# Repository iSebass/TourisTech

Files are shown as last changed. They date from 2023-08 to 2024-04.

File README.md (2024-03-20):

# TuristTech

## Introducción

En el contexto de un mundo cada vez más consciente de la importancia de la sostenibilidad y la conservación del medio ambiente, surge un proyecto visionario que busca revolucionar la industria del ecoturismo en Colombia. En este proyecto encontrarás la implementación de una red IoT para monitorear y controlar dispositivos en un ecotel, uniendo la tecnología con la conservación del entorno natural.

## Metodología 

En el marco de este proyecto, la metodología establece las fases fundamentales desde la planificación inicial hasta la culminación del proceso, garantizando una gestión eficaz y coherente en cada etapa. Esta metodología se sustenta en la colaboración interdisciplinaria entre especialistas en tecnología, turismo y conservación, integrando además prácticas ágiles y flexibles para ajustarse a las exigencias y dinámicas del entorno en constante cambio. 

1. **Implementación de Alexa**: La implementación de Alexa marca un avance significativo en el proyecto, al ofrecer una interacción innovadora para los usuarios del ecotel. Este punto de la metodología se enfoca en dos etapas cruciales:
   
    1. **Configuración inicial de Alexa**: Se trata de preparar y conectar los dispositivos necesarios, configurar la aplicación y la cuenta asociada. Esta etapa establece la base tecnológica esencial para la interacción con el asistente de voz. Para la configuración inicial de Alexa, se deben seguir los siguientes pasos:
   
       1. **Descargar la aplicación de Alexa:**
          - Si estás usando un dispositivo Android, descarga la aplicación de Alexa desde [Google Play Store](https://play.google.com/store/apps/details?id=com.amazon.dee.app&pcampaignid=web_share "Google Play Store").
          - Si utilizas un dispositivo Apple, encuentra la aplicación en [App Store](https://apps.apple.com/ni/app/amazon-alexa/id944011620 "App Store").
       
       2. **Vincular o registrar una cuenta de Amazon:**
          - Si aún no tienes una cuenta de Amazon, regístrate.
          - Inicia sesión con tu cuenta de Amazon en la aplicación de Alexa.
       
       3. **Instalar una Skill:**
          - Dentro de la aplicación de Alexa, dirígete a la sección de "Skills" y selecciona "Buscar Skills".
          - Busca la Skill "Ben Hardill - Node-RED" o utiliza este [enlace directo](https://www.amazon.com/Ben-Hardill-Node-RED/dp/B01N0D97FZ) para instalarla.
          - Una vez instalada, sigue las instrucciones para habilitar la Skill y conceder los permisos necesarios para vincular Alexa con Node-RED.
 
   2. **Integración de Alexa con Node-RED**: Aquí, se exploran los pasos para conectar Alexa a Node-RED, una plataforma que facilita la automatización y el control de dispositivos IoT. Se configuran los nodos correspondientes para una comunicación efectiva entre ambos sistemas.

Estas etapas son fundamentales para aprovechar al máximo la implementación de Alexa, mejorando la experiencia del ecoturismo. Una cuidadosa planificación y ejecución en estas áreas sientan las bases para una integración exitosa del asistente de voz en el entorno del ecotel.

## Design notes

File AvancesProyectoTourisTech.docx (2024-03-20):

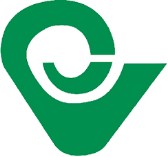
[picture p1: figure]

# UNIDAD CENTRAL DEL VALLE DEL CAUCA - VICEREPTORIA DE INVESTIGACIÓN Y PROYECCIÓN SOCIAL

### AULA STEAM- INFORME TOURISTECH

Abstract: This project focuses on implementing an IoT network to monitor and control devices in an ecotel, aiming to integrate technology with environmental conservation in Colombia. Although not yet implemented in a real ecotourism environment, significant progress has been made with a pilot model at Universidad Central del Valle. Using ESP32 devices, a Mosquito broker, a Node-RED dashboard, and Alexa voice assistance, control of room lighting and visualization of environmental variables have been achieved. The project stands out for its ability to enhance visitor experience while promoting natural resource conservation.

Resumen: El proyecto consiste en la implementación de una red IoT para monitorear y controlar dispositivos en un ecotel, con el objetivo de unir la tecnología con la conservación del entorno natural en Colombia. Aunque aún no se ha materializado en un entorno ecoturístico real, se ha avanzado significativamente con un modelo piloto en la Universidad Central del Valle. Utilizando dispositivos ESP32, un broker Mosquito, una dashboard en Node-RED y la asistencia de voz de Alexa, se ha logrado controlar la iluminación de las habitaciones y visualizar variables ambientales. El proyecto destaca por su capacidad para mejorar la experiencia del visitante mientras se promueve la conservación de los recursos naturales.

I. INTRODUCCIÓN

En el contexto de un mundo cada vez más consciente de la importancia de la sostenibilidad y la conservación del medio ambiente, surge un proyecto visionario que busca revolucionar la industria del ecoturismo en Colombia. Este informe presenta los progresos y adelantos alcanzados en la creación de un concepto innovador: la implementación de una red IoT para monitorear y controlar dispositivos en un ecotel, uniendo la tecnología con la conservación del entorno natural.

Aunque el proyecto aún no se ha materializado en un entorno ecoturístico real, se ha logrado un avance significativo mediante la creación de un modelo piloto en el aula STEAM de la Vicerrectoría de Investigación de la Universidad Central del Valle. Este espacio de vanguardia ha servido como campo de pruebas para explorar las posibilidades y desafíos de integrar la tecnología IoT en un entorno de ecoturismo.

El proyecto se basa en la utilización de dispositivos ESP32 con conectividad WiFi, junto con un broker Mosquito y una dashboard desarrollada en Node-RED, para crear una red robusta y versátil. Además, se ha implementado la asistencia de voz a través de

Alexa, agregando una capa de interacción intuitiva para los usuarios.

A pesar de su ubicación en un entorno académico, el proyecto ha logrado avances significativos, incluyendo la capacidad de controlar la iluminación de las habitaciones y visualizar variables ambientales como temperatura, altitud, presión y calidad del aire. Estos logros sientan las bases para futuras aplicaciones en el campo del ecoturismo, ofreciendo un enfoque innovador que busca conciliar la comodidad de los visitantes con la preservación del medio ambiente.

Este informe detallará los aspectos técnicos del proyecto, así como los pasos a seguir para llevarlo del laboratorio al campo. Se discutirán los desafíos enfrentados durante el proceso de desarrollo y se explorarán las oportunidades para expandir y perfeccionar el proyecto. Se analizarán también los beneficios potenciales que esta iniciativa puede aportar tanto a la industria del ecoturismo como al medio ambiente en general, destacando su capacidad para mejorar la experiencia del visitante mientras se promueve la conservación de los recursos naturales.

Aunque el camino hacia la implementación completa en un ecotel real presenta desafíos adicionales, el modelo piloto desarrollado en la Universidad Central del Valle representa un paso crucial en la dirección correcta. La colaboración entre expertos en tecnología, conservación y turismo ha sido fundamental para impulsar este proyecto hacia adelante y sentar las bases para su éxito futuro.

En resumen, este informe proporcionará una visión detallada de un proyecto innovador que tiene el potencial de transformar la industria del ecoturismo en Colombia y más allá. A medida que avanzamos hacia un futuro más sostenible, iniciativas como esta demuestran el poder de la tecnología para impulsar el cambio positivo y proteger nuestro precioso entorno natural para las generaciones venideras.

## II. METODOLOGÍA

Implementación de Alexa

1. Registra la misma cuenta de amazon a la pagina que nos proporciona nodered de el nodo de Alexa.
2. Se crea uno dispositivo en el cual se especifica el nombre, el tipo de funcion y la descripción.
3. Se le instala a la Alexa la aplicación de node red para permitir la conexión con el nodo en Node red
4. Se configura a Alexa para que busque nuevos dispositivos en donde aparecerá los creamos anteriormente en la cuenta de nodered-alexa

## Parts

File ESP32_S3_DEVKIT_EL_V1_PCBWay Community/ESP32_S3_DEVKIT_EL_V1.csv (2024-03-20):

Item | Qty | Reference(s) | Product Number | Value | LibPart | Footprint | Datasheet | DNP | Description | Manufacturer | Price
1 | 6 | BT1, BT2, BT3, BT4, SW1, SW2 | PTS636 SK25 SMTR LFS | SW_Push | Switch:SW_Push | Button_Switch_SMD:SW_Tactile_SPST_NO_Straight_CK_PTS636Sx25SMTRLFS | https://www.ckswitches.com/media/2779/pts636.pdf |  | Tactile Switch SPST-NO Top Actuated Surface Mount | C&K | 0.15
2 | 1 | BZ1 | GT-111P | Buzzer | Device:Buzzer | Buzzer_Beeper:Buzzer_12x9.5RM7.6 | https://www.digikey.com/en/supplier-centers/soberton |  | Buzzers Transducer, Externally Driven Magnetic 1.5 V 10mA 2.048kHz 80dB @ 1.5V, 10cm Through Hole PC Pins | Soberton Inc. | 0.65
3 | 10 | C1, C3, C5, C6, C7, C8, C10, C11, C13, C14 | C0603C104K5RAC7867 | 0.1 uF | Device:C | Capacitor_SMD:C_0603_1608Metric_Pad1.08x0.95mm_HandSolder | https://connect.kemet.com:7667/gateway/IntelliData-ComponentDocumentation/1.0/download/datasheet/C0603C104K5RACTU |  | CAP CER 0.1UF 50V X7R 0603 | KEMET | 0.11
4 | 3 | C2, C9, C12 | C1206C106M3PAC7800 | 10 uF | Device:C | Capacitor_SMD:C_1206_3216Metric_Pad1.33x1.80mm_HandSolder | https://connect.kemet.com:7667/gateway/IntelliData-ComponentDocumentation/1.0/download/datasheet/C1206C106M3PACTU |  | CAP CER 10UF 25V X5R 1206 | KEMET | 0.27
5 | 1 | C4 | C1206C105M4RAC7800 | 1 uF | Device:C | Capacitor_SMD:C_1206_3216Metric_Pad1.33x1.80mm_HandSolder | https://connect.kemet.com:7667/gateway/IntelliData-ComponentDocumentation/1.0/download/datasheet/C1206C105M4RAC7800 |  | 1 µF ±20% 16V Ceramic Capacitor X7R 1206 (3216 Metric) | KEMET | 0.17
6 | 1 | D1 | 5988270107F | Green LED | Device:LED | LED_SMD:LED_1206_3216Metric | https://s3-us-west-2.amazonaws.com/catsy.557/Dialight_CBI_data_598-1206_Apr2018.pdf |  | Green 566nm LED Indication - Discrete 2V 1206 (3216 Metric) | Dialight | 0.32
7 | 1 | D2 | NRVA4007T3G | NRVA4007T3G | Diode:MRA4007T3G | Diode_SMD:D_SMA | https://www.onsemi.com/pdf/datasheet/mra4003t3-d.pdf |  | Diode 1000 V 1A Surface Mount SMA | onsemi | 0.41
8 | 4 | D3, D4, D5, D6 | COM-16347 | WS2812B | LED:WS2812B | LED_SMD:LED_WS2812B_PLCC4_5.0x5.0mm_P3.2mm | https://cdn-shop.adafruit.com/datasheets/WS2812B.pdf |  | Addressable Lighting - LED Serial NRZ (Shift Register) Red, Green, Blue (RGB) | SparkFun Electronics | 0.58
9 | 4 | D7, D8, D9, D10 | 5988291107F | Blue LED | Device:LED | LED_SMD:LED_1206_3216Metric | https://s3-us-west-2.amazonaws.com/catsy.557/Dialight_CBI_data_598-1206_Apr2018.pdf |  | Blue 473nm LED Indication - Discrete 3.2V 1206 (3216 Metric) | Dialight | 0.38
10 | 3 | D11, D12, D13 | STPS2L30A | D_Schottky | Device:D_Schottky | Diode_SMD:D_SMA | https://www.st.com/content/ccc/resource/technical/document/datasheet/62/6b/2e/7f/34/cb/43/55/CD00001633.pdf/files/CD00001633.pdf/jcr:content/translations/en.C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 |  | DIODE SCHOTTKY 30V 2A SMA | STMicroelectronics | 0.36
11 | 1 | D14 | 5988210107F | RED LED | Device:LED | LED_SMD:LED_1206_3216Metric | https://s3-us-west-2.amazonaws.com/catsy.557/Dialight_CBI_data_598-1206_Apr2018.pdf |  | Red 635nm LED Indication - Discrete 2V 1206 (3216 Metric) | Dialight | 0.33
12 | 3 | J1, J4, J5 | 2057-BHR-06-VUA-ND | Conn_02x03_IDC | Connector_Generic:Conn_02x03_Odd_Even | Connector_IDC:IDC-Header_2x03_P2.54mm_Vertical | https://app.adam-tech.com/products/download/data_sheet/203218/bhr-xx-vua-data-sheet.pdf |  | Connector Header Through Hole 6 position 0.100" (2.54mm) | Adam Tech | 0.25
13 | 2 | J2, J8 | 0473460001 | USB_B_Micro | Connector:USB_B_Micro | Connector_USB:USB_Micro-B_Molex_47346-0001 | https://tools.molex.com/pdm_docs/sd/473460001_sd.pdf |  | CONN RCPT USB2.0 MICRO B SMD R/A | Molex | 1.17
14 | 2 | J3, J6 | 1734656 | Screw_Terminal_01x02 | Connector:Screw_Terminal_01x02 | TerminalBlock_Phoenix:TerminalBlock_Phoenix_MKDS-1,5-2_1x02_P5.00mm_Horizontal | https://media.digikey.com/PDF/Data%20Sheets/Phoenix%20Contact%20PDFs/1734656.pdf |  | 2 Position Wire to Board Terminal Block Horizontal with Board 0.197" (5.00mm) Through Hole | Phoenix Contact | 1.26
15 | 1 | J7 | 54202-S0803LF | Conn_02x03_Odd_Even | Connector_Generic:Conn_02x03_Odd_Even | Connector_PinHeader_2.54mm:PinHeader_2x03_P2.54mm_Vertical_SMD | https://cdn.amphenol-cs.com/media/wysiwyg/files/drawing/54202.pdf |  | Connector Header Surface Mount 6 position 0.100" (2.54mm) | Amphenol ICC (FCI) | 0.45
16 | 1 | J9 | ED1543-ND | Conn_02x05_Odd_Even | Connector_Generic:Conn_02x05_Odd_Even | Connector_IDC:IDC-Header_2x05_P2.54mm_Vertical | http://www.on-shore.com/wp-content/uploads/2018/04/302-SXX1.pdf |  | Connector Header Through Hole 10 position 0.100" (2.54mm) | On Shore Technology Inc. | 0.33
17 | 1 | K1 | G5Q-1A4 DC5 | G5Q-1A | Relay:G5Q-1A | Relay_THT:Relay_SPST_Omron-G5Q-1A | https://www.omron.com/ecb/products/pdf/en-g5q.pdf |  | General Purpose Relay SPST-NO (1 Form A) 5VDC Coil Through Hole | Omron Electronics Inc-EMC Div | 1.57
18 | 3 | Q1, Q2, Q3 | MMBT2222LT1G | Q_NPN_BEC | Device:Q_NPN_BEC | Package_TO_SOT_SMD:SOT-23-3 | https://www.onsemi.com/pdf/datasheet/mmbt2222lt1-d.pdf |  | Bipolar (BJT) Transistor NPN 30 V 600 mA 250MHz 300 mW Surface Mount SOT-23-3 (TO-236) | onsemi | 0.16
19 | 4 | R1, R2, R3, R5 | ERJ-P08J102V | 1K | Device:R_US | Resistor_SMD:R_1206_3216Metric | https://industrial.panasonic.com/ww/products/pt/general-purpose-chip-resistors/models/ERJ-P08J102V |  | RES SMD 1K OHM 5% 2/3W 1206 | Panasonic Electronic Components | 0.14
20 | 1 | R4 | ERJ-8GEY0R00V | 0R | Device:R_US | Resistor_SMD:R_1206_3216Metric | https://industrial.panasonic.com/ww/products/pt/general-purpose-chip-resistors/models/ERJ8GEYJ331V |  | 0 Ohms Jumper Chip Resistor 1206 (3216 Metric) Automotive AEC-Q200 Thick Film | Panasonic Electronic Components | 0.14
21 | 4 | R6, R7, R12, R13 | ERJ-8GEYJ103V | 10K | Device:R_US | Resistor_SMD:R_1206_3216Metric | https://industrial.panasonic.com/ww/products/pt/general-purpose-chip-resistors/models/ERJ-8GEYJ103V |  | RES SMD 10K OHM 5% 1/4W 1206 | Panasonic Electronic Components | 0.12
22 | 6 | R8, R9, R10, R11, R14, R15 | ERJ-8GEYJ331V | 330R | Device:R_US | Resistor_SMD:R_1206_3216Metric | https://industrial.panasonic.com/ww/products/pt/general-purpose-chip-resistors/models/ERJ8GEYJ331V |  | RES SMD 330 OHM 5% 1/4W 1206 | Panasonic Electronic Components | 0.14
23 | 4 | RV1, RV2, RV3, RV4 | 3386P-1-104LF | 100K | Device:R_Potentiometer_Trim_US | Potentiometer_THT:Potentiometer_Bourns_3386P_Vertical | https://www.vishay.com/docs/51016/t73.pdf |  | 100 kOhms 0.5W, 1/2W PC Pins Through Hole Trimmer Potentiometer Cermet 1.0 Turn Top Adjustment | Bourns Inc. | 1.61
24 | 1 | U1 | CH340C | CH340C | Interface_USB:CH340C | Package_SO:SOIC-16_3.9x9.9mm_P1.27mm | https://datasheet.lcsc.com/szlcsc/Jiangsu-Qin-Heng-CH340C_C84681.pdf |  | USB to serial port chip | WCH | 0.73
25 | 1 | U2 | ESP32-S3-WROOM-1-N8R2 | ESP32-S3-WROOM-1 | PCM_Espressif:ESP32-S3-WROOM-1 | PCM_Espressif:ESP32-S3-WROOM-1 | https://www.espressif.com/sites/default/files/documentation/esp32-s3-wroom-1_wroom-1u_datasheet_en.pdf |  | WiFi 802.11a/b/g/n, Bluetooth v5.0 Transceiver Module 2.4GHz PCB Trace | Espressif Systems | 3.35
26 | 1 | U3 | AZ1117CH-3.3TRG1 | 3.3v 1A | Regulator_Linear:AZ1117-3.3 | Package_TO_SOT_SMD:SOT-223-3_TabPin2 | https://www.diodes.com/assets/Datasheets/AZ1117C.pdf |  | IC REG LINEAR 3.3V 1A SOT223 | Diodes Incorporated | 0.45

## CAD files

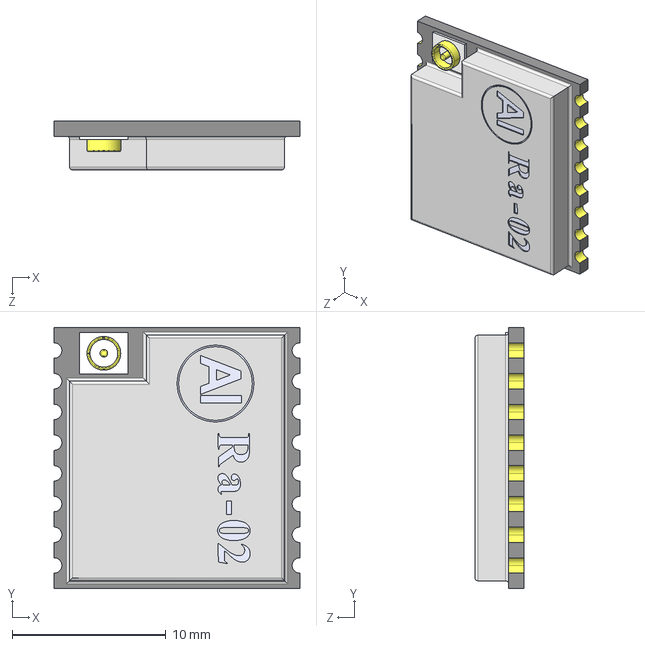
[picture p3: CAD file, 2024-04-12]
ESP32_S3_DEVKIT_EL_V1_PCBWay Community/3D MODELS/User Library-RA-02-2.STEP
16.0 x 17.0 x 3.20 mm

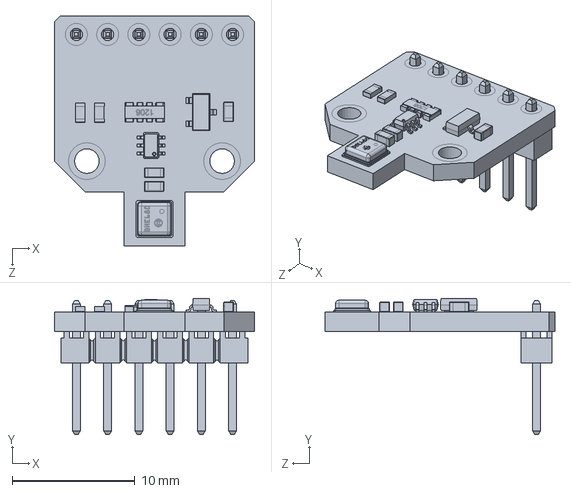
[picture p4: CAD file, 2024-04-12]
PCB/ProyectoTuristech Modulo 01/Modelos3d/CJMCU-680.SLDPRT
16.3 x 11.1 x 18.7 mm

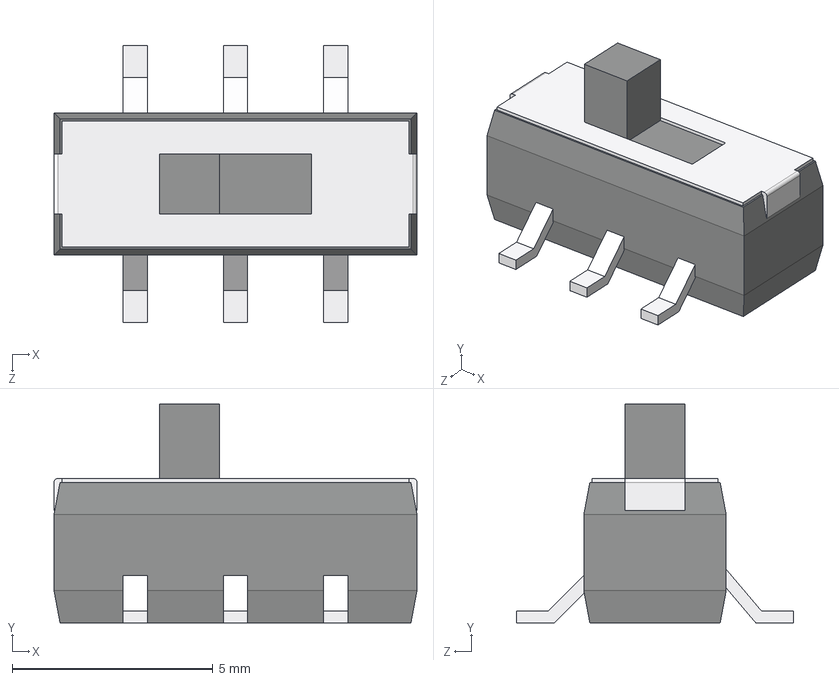
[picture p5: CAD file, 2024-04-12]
ESP32_S3_DEVKIT_EL_V1_PCBWay Community/3D MODELS/User Library-smd_slide_switch.STEP
9.05 x 5.45 x 6.90 mm

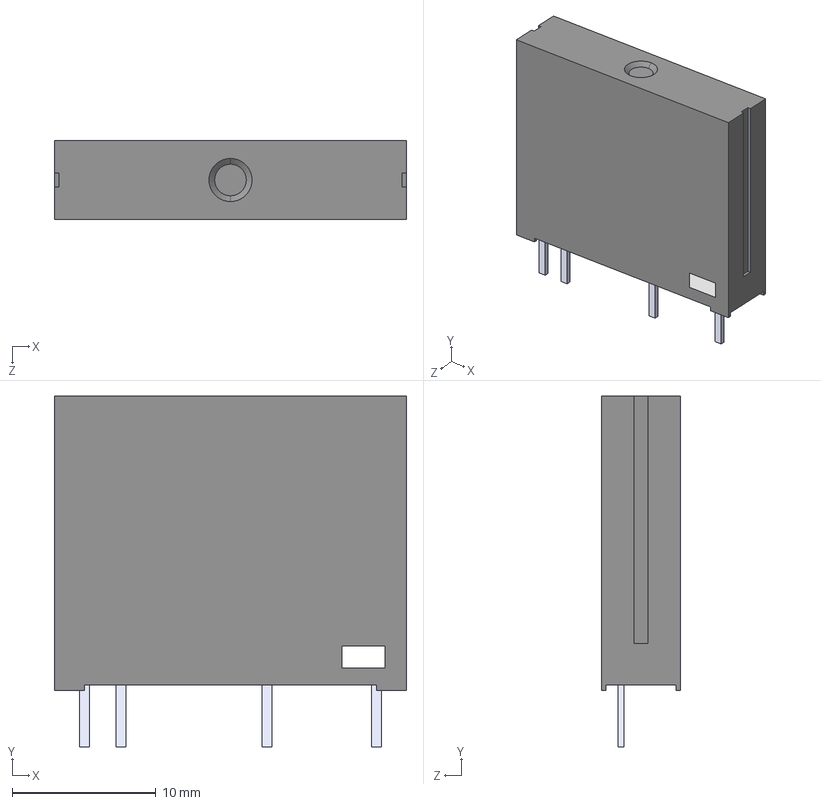
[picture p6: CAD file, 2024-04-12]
PCB/ProyectoTuristech Modulo 01/Modelos3d/G3MB-202P.step
24.5 x 24.4 x 5.50 mm

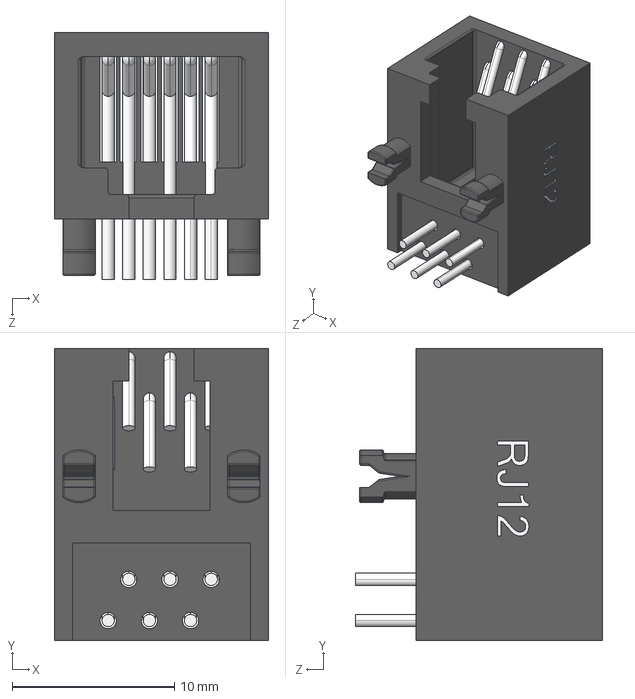
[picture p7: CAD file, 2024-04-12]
ESP32_S3_DEVKIT_EL_V1_PCBWay Community/3D MODELS/User Library-RJ12_54601-906WPLF.STEP
13.2 x 18.0 x 15.2 mm

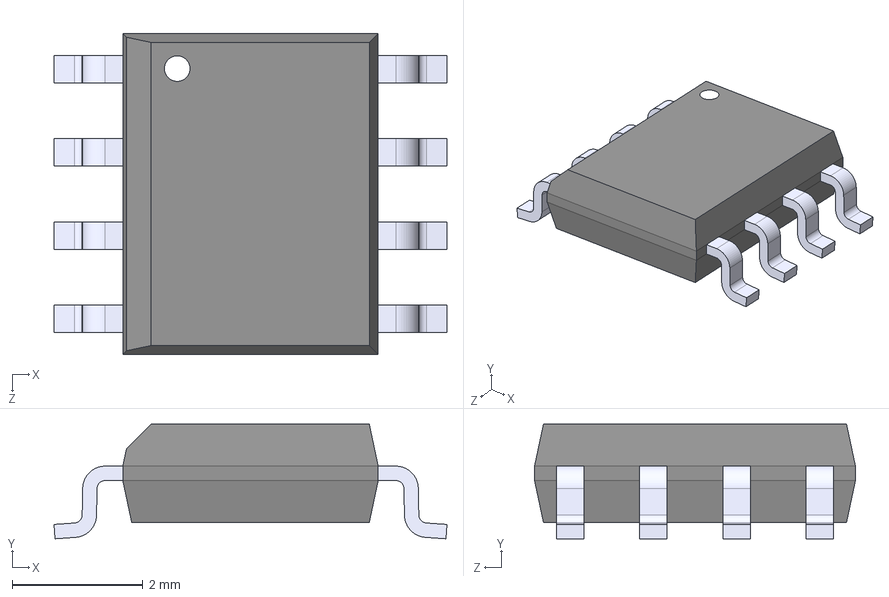
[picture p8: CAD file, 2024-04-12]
ESP32_S3_DEVKIT_EL_V1_PCBWay Community/3D MODELS/LM393D.STEP
6.00 x 1.75 x 4.90 mm

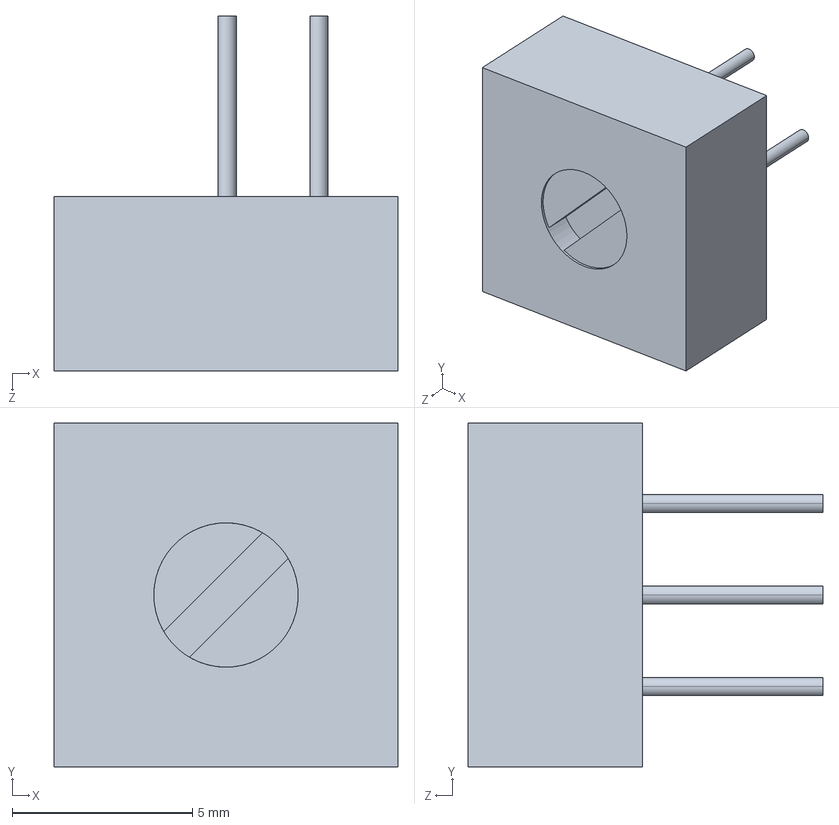
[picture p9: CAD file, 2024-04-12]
ESP32_S3_DEVKIT_EL_V1_PCBWay Community/3D MODELS/CircuitWorks-CERMET TRIMMER SINGLE TURN 10MM 500MW TOP ADJUST 1.STEP
9.53 x 9.53 x 9.83 mm

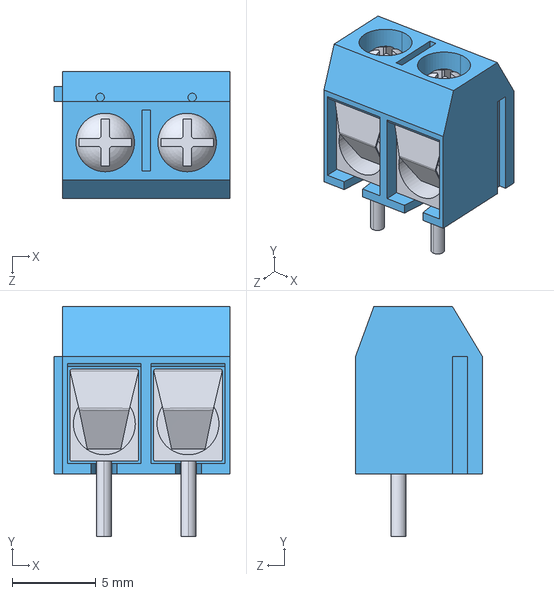
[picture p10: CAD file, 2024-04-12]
ESP32_S3_DEVKIT_EL_V1_PCBWay Community/3D MODELS/User Library-bornera-1.STEP
10.5 x 13.8 x 7.60 mm

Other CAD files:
ESP32_S3_DEVKIT_EL_V1_PCBWay Community/3D MODELS/CircuitWorks-CERMET TRIMMER SINGLE TURN 10MM 500MW TOP ADJUST.STEP

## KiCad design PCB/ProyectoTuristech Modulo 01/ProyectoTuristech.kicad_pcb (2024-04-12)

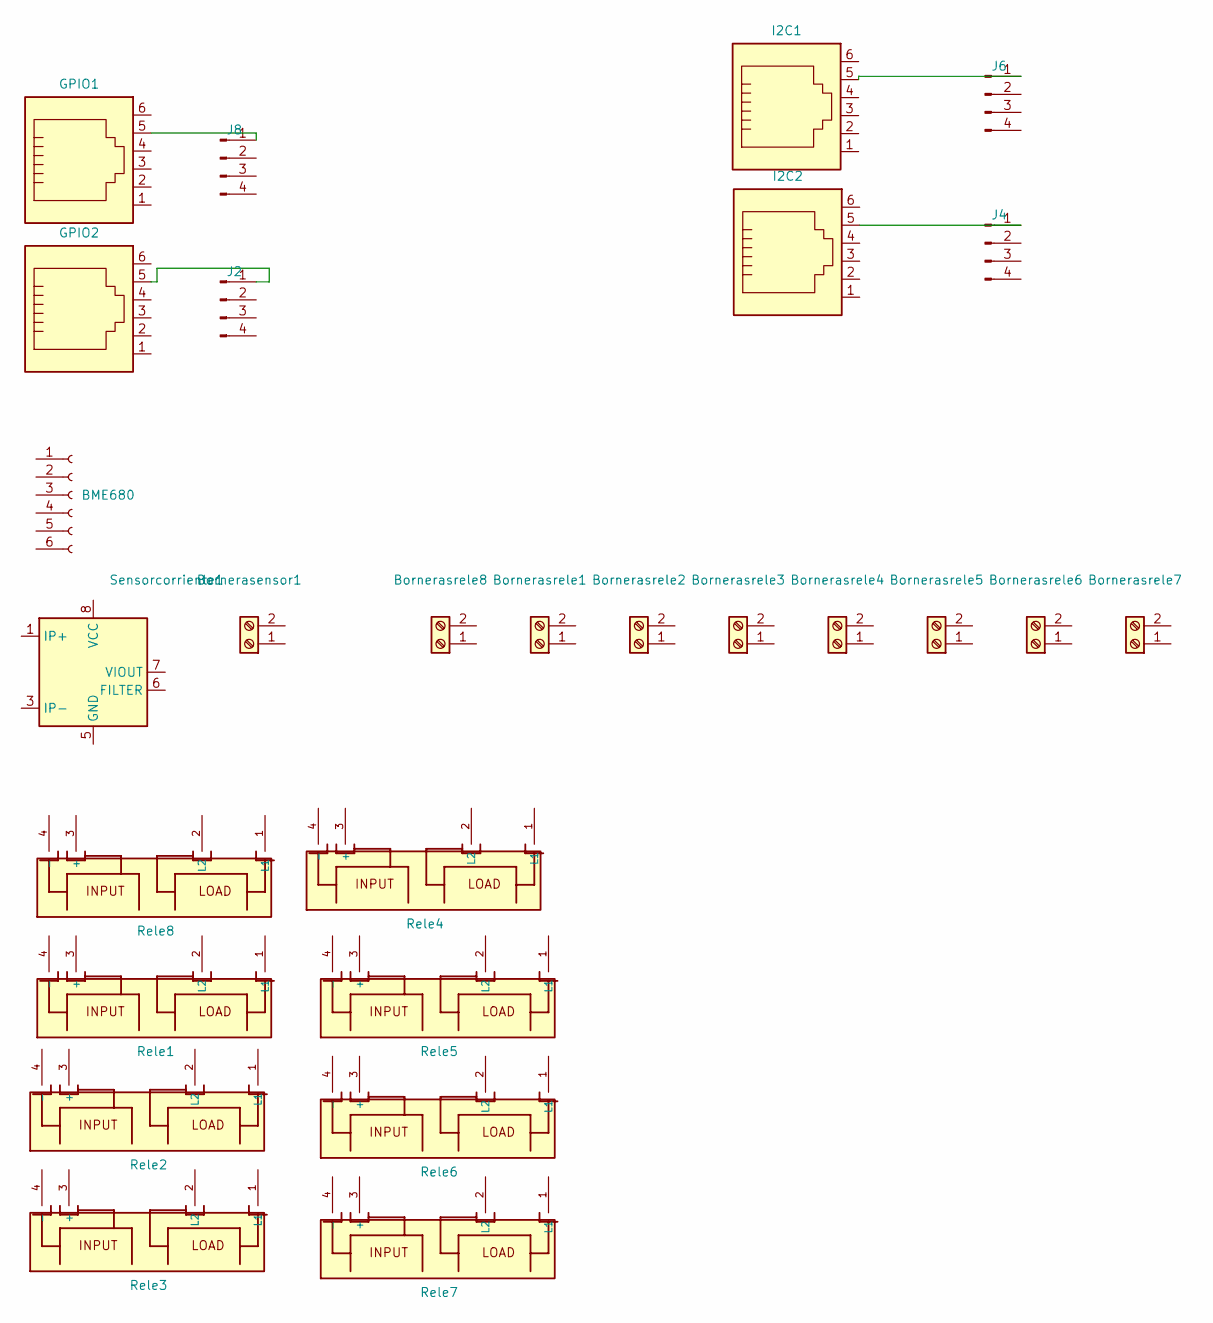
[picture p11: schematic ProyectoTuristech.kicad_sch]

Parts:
BME680: Conn_01x06_Socket; PinSocket_1x06_P2.54mm_Vertical
Bornerasensor1: Screw_Terminal_01x02; TerminalBlock_WAGO_236-102_1x02_P5.00mm_45Degree
Bornerasrele1, Bornerasrele2, Bornerasrele3, Bornerasrele4, Bornerasrele5, Bornerasrele6, Bornerasrele7, Bornerasrele8: Screw_Terminal_01x02; TerminalBlock_WAGO_236-102_1x02_P5.00mm_45Degree
GPIO1, GPIO2: 6P6C; RJ25_Wayconn_MJEA-660X1_Horizontal
I2C1, I2C2: 6P6C; RJ25_Wayconn_MJEA-660X1_Horizontal
J2, J4, J6, J8: Conn_01x04_Pin; PinSocket_1x04_P2.54mm_Vertical
Rele1, Rele2, Rele3, Rele4, Rele5, Rele6, Rele7, Rele8: G3MB-202P; RELAY_G3MB-202P
Sensorcorriente1: ACS712xLCTR-30A; SOIC-8_3.9x4.9mm_P1.27mm

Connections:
unnamed: GPIO2.5, J2.1
unnamed: I2C2.5, J4.1
unnamed: I2C1.5, J6.1
unnamed: GPIO1.5, J8.1
unnamed: Sensorcorriente1.1 (IP+), Sensorcorriente1.2 (IP+)
unnamed: Sensorcorriente1.3 (IP-), Sensorcorriente1.4 (IP-)

Board: 2 copper layers, 27 parts (0 on the bottom side), 6 nets, no tracks yet.

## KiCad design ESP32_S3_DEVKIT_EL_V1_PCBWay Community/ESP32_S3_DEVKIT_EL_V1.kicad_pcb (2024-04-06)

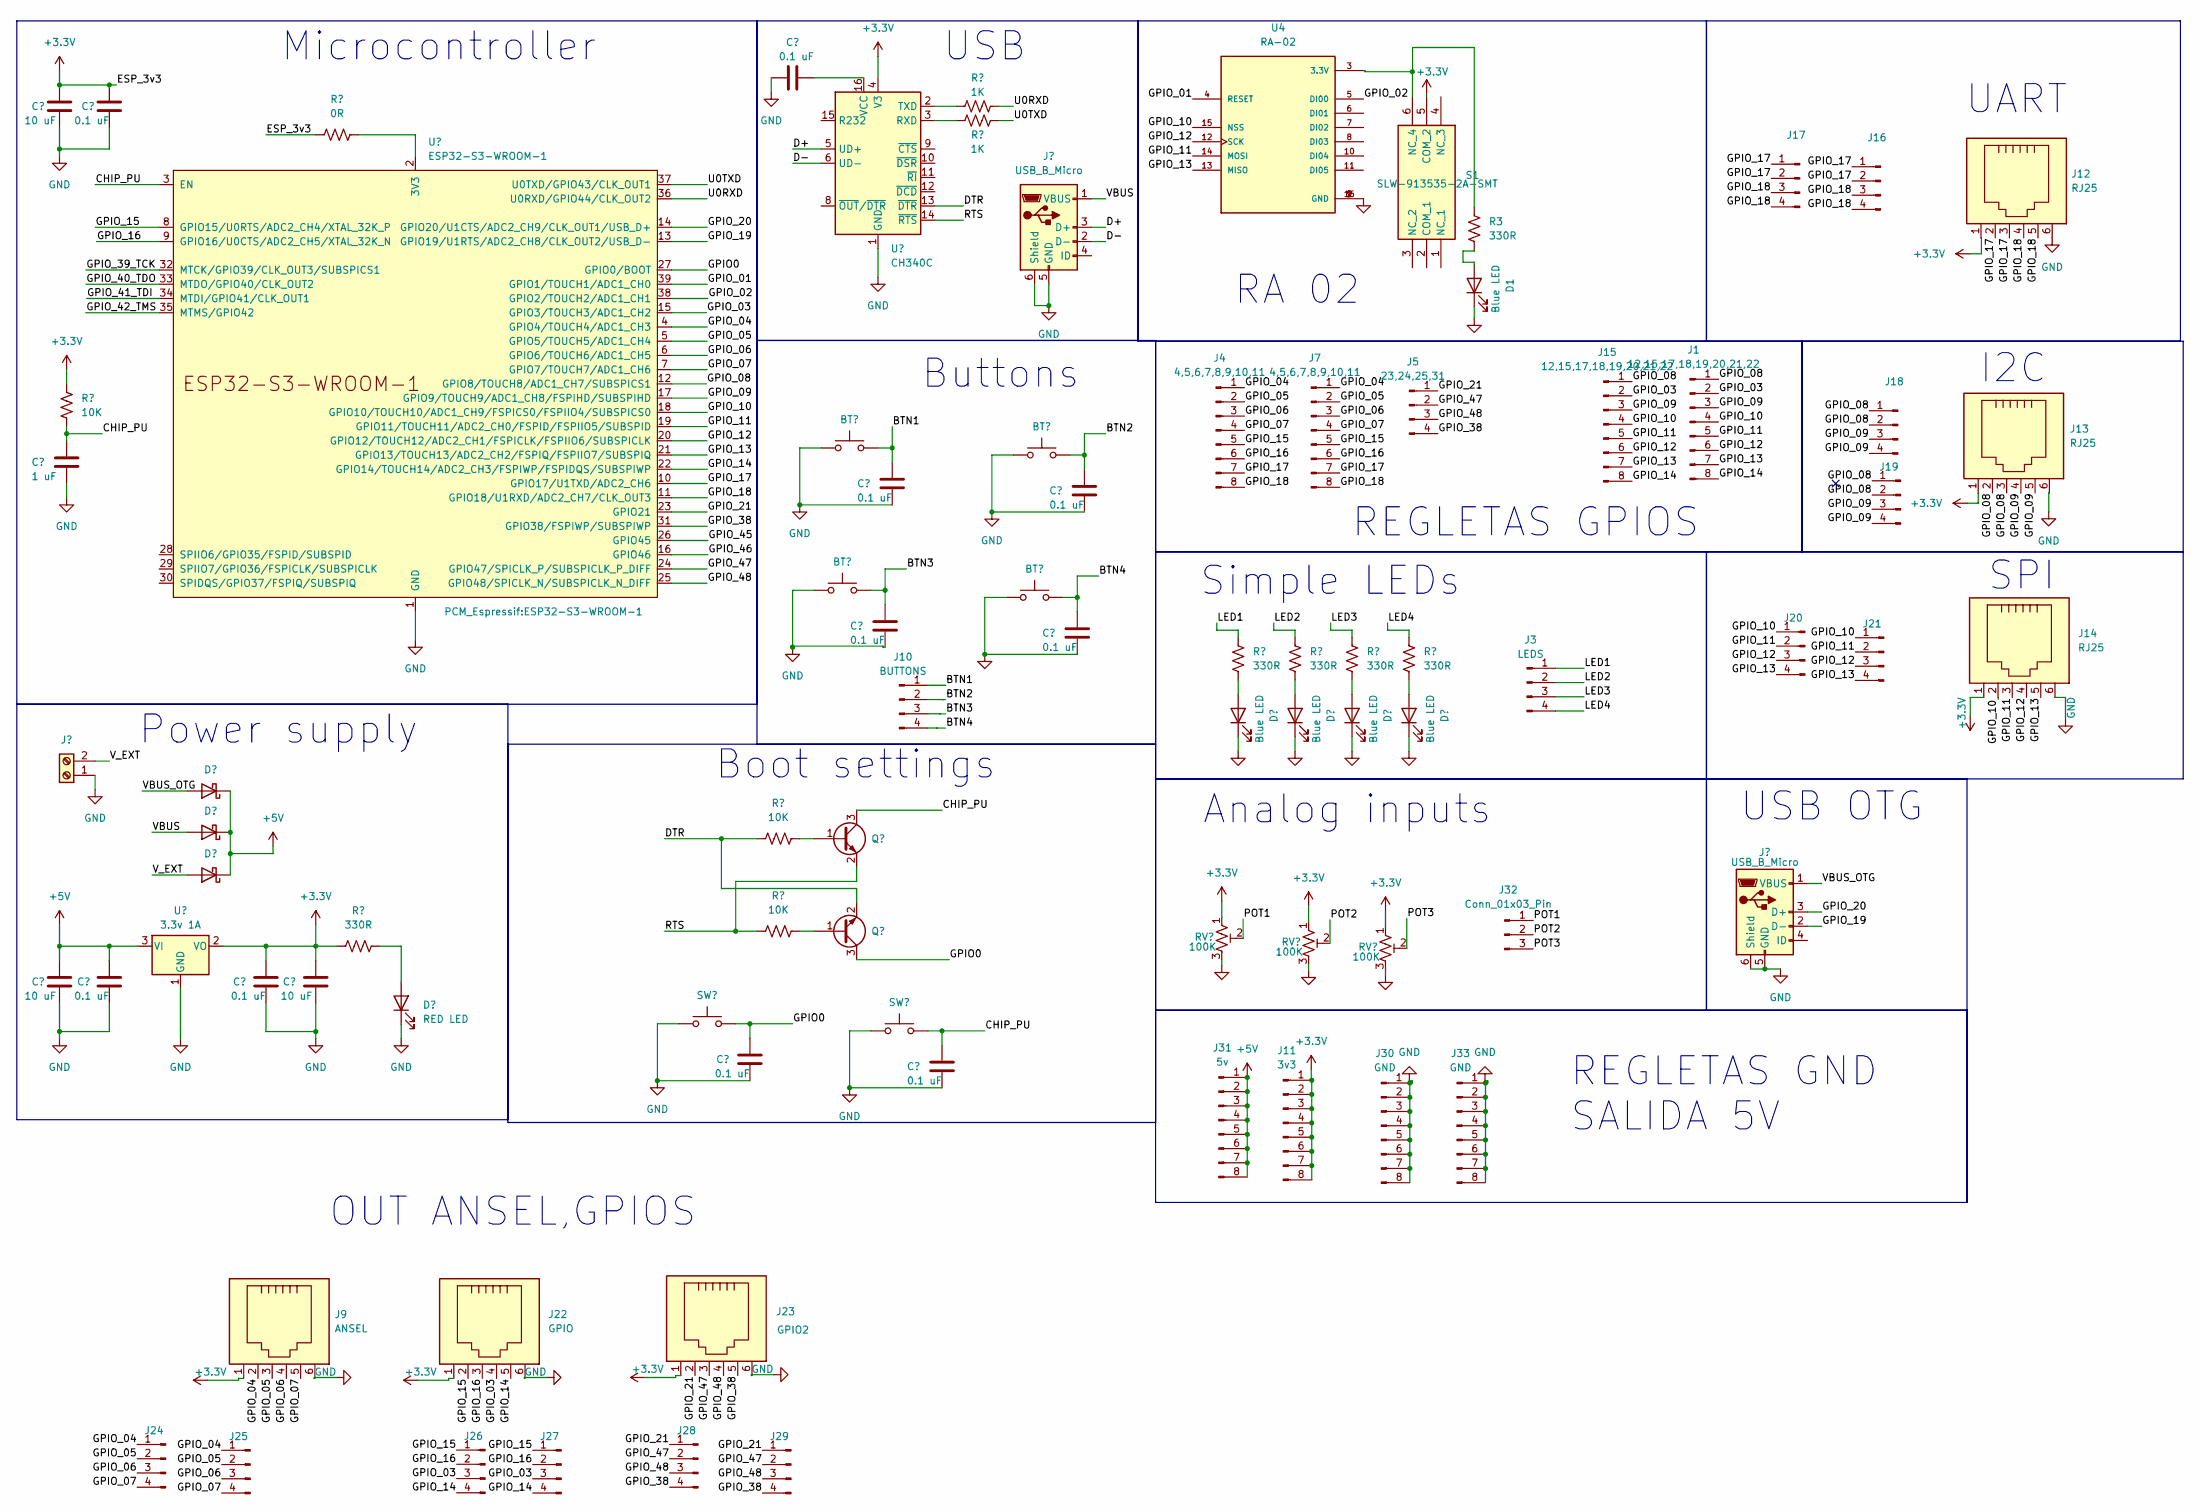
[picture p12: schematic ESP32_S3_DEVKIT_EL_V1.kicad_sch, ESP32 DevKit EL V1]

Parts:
BT1, BT2, BT3, BT4: SW_Push; SW_Tactile_SPST_NO_Straight_CK_PTS636Sx25SMTRLFS
C1, C3, C5, C6, C7, C8, C10, C11, C13, C14: 0.1 uF; C_0603_1608Metric_Pad1.08x0.95mm_HandSolder
C2, C9, C12: 10 uF; C_1206_3216Metric_Pad1.33x1.80mm_HandSolder
C4: 1 uF; C_1206_3216Metric_Pad1.33x1.80mm_HandSolder
D1, D7, D8, D9, D10: Blue LED; LED_1206_3216Metric
D11, D12, D13: D_Schottky; D_SMA
D14: RED LED; LED_1206_3216Metric
J1, J15: 12,15,17,18,19,20,21,22; PinHeader_1x08_P2.54mm_Vertical
J2, J8: USB_B_Micro; USB_Micro-B_Molex_47346-0001
J3: LEDS; PinHeader_1x04_P2.54mm_Vertical
J4, J7: 4,5,6,7,8,9,10,11; PinHeader_1x08_P2.54mm_Vertical
J5: 23,24,25,31; PinHeader_1x04_P2.54mm_Vertical
J6: Screw_Terminal_01x02; TerminalBlock_Phoenix_MKDS-1,5-2_1x02_P5.00mm_Horizontal
J9: ANSEL; RJ25_Wayconn_MJEA-660X1_Horizontal
J10: BUTTONS; PinHeader_1x04_P2.54mm_Vertical
J11: 3v3; PinHeader_1x08_P2.54mm_Vertical
J12, J13, J14: RJ25; RJ25_Wayconn_MJEA-660X1_Horizontal
J16, J17, J18, J19, J20, J21, J24, J25, J26, J27, J28, J29: PinHeader_1x04_P2.54mm_Vertical
J22: GPIO; RJ25_Wayconn_MJEA-660X1_Horizontal
J23: GPIO2; RJ25_Wayconn_MJEA-660X1_Horizontal
J30, J33: GND; PinHeader_1x08_P2.54mm_Vertical
J31: 5v; PinHeader_1x08_P2.54mm_Vertical
J32: Conn_01x03_Pin; PinHeader_1x03_P2.54mm_Vertical
Q2, Q3: Q_NPN_BEC; SOT-23-3
R1, R2: 1K; R_1206_3216Metric
R3, R8, R9, R10, R11, R14: 330R; R_1206_3216Metric
R4: 0R; R_1206_3216Metric
R7, R12, R13: 10K; R_1206_3216Metric
RV1, RV2, RV3: 100K; Potentiometer_Bourns_3386P_Vertical
S1: SLW-913535-2A-SMT; SLW9135352ASMT; Mouser Part Number 179-SLW-913535-2ASMT
SW1, SW2: SW_Push; SW_Tactile_SPST_NO_Straight_CK_PTS636Sx25SMTRLFS
U1: CH340C; SOIC-16_3.9x9.9mm_P1.27mm
U2: ESP32-S3-WROOM-1
U3: 3.3v 1A; SOT-223-3_TabPin2
U4: RA-02

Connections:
+3.3V: C2.1, C3.1, C11.1, C12.1, J9.1, J11.1, J11.2, J11.3, J11.4, J11.5, J11.6, J11.7, J11.8, J12.1, J13.1, J14.1, J22.1, J23.1, R4.1, R7.2, R14.1, RV1.1, RV2.1, RV3.1, S1.5 (COM_2), U1.4 (V3), U3.2 (VO); also elsewhere on the board
+5V: C9.1, C10.1, D11.1 (K), D12.1 (K), D13.1 (K), J31.1, J31.2, J31.3, J31.4, J31.5, J31.6, J31.7, J31.8, U3.3 (VI)
/BTN1: BT1.2, C5.1, J10.1
/BTN2: BT2.2, C6.1, J10.2
/BTN3: BT3.2, C7.1, J10.3
/BTN4: BT4.2, C8.1, J10.4
/CHIP_PU: C4.1, C14.1, Q2.3 (C), R7.1, SW2.2, U2.3 (EN); also elsewhere on the board
/D+: J2.3 (D+), U1.5 (UD+)
/D-: J2.2 (D-), U1.6 (UD-)
/DTR: Q3.2 (E), R12.1, U1.13 (~DTR)
/GPIO0: C13.1, Q3.3 (C), SW1.2, U2.27 (GPIO0/BOOT); also elsewhere on the board
/GPIO_01: U2.39 (GPIO1/TOUCH1/ADC1_CH0), U4.4 (RESET)
/GPIO_02: U2.38 (GPIO2/TOUCH2/ADC1_CH1), U4.5 (DI00)
/GPIO_03: J1.2, J15.2, J22.4, J26.3, J27.3, U2.15 (GPIO3/TOUCH3/ADC1_CH2)
/GPIO_04: J4.1, J7.1, J9.2, J24.1, J25.1, U2.4 (GPIO4/TOUCH4/ADC1_CH3)
/GPIO_05: J4.2, J7.2, J9.3, J24.2, J25.2, U2.5 (GPIO5/TOUCH5/ADC1_CH4)
/GPIO_06: J4.3, J7.3, J9.4, J24.3, J25.3, U2.6 (GPIO6/TOUCH6/ADC1_CH5)
/GPIO_07: J4.4, J7.4, J9.5, J24.4, J25.4, U2.7 (GPIO7/TOUCH7/ADC1_CH6)
/GPIO_08: J1.1, J13.2, J13.3, J15.1, J18.1, J18.2, J19.1, J19.2, U2.12 (GPIO8/TOUCH8/ADC1_CH7/SUBSPICS1)
/GPIO_09: J1.3, J13.4, J13.5, J15.3, J18.3, J18.4, J19.3, J19.4, U2.17 (GPIO9/TOUCH9/ADC1_CH8/FSPIHD/SUBSPIHD)
/GPIO_10: J1.4, J14.2, J15.4, J20.1, J21.1, U2.18 (GPIO10/TOUCH10/ADC1_CH9/FSPICS0/FSPIIO4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), U4.15 (NSS)
/GPIO_11: J1.5, J14.3, J15.5, J20.2, J21.2, U2.19 (GPIO11/TOUCH11/ADC2_CH0/FSPID/FSPIIO5/S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), U4.14 (MOSI)
/GPIO_12: J1.6, J14.4, J15.6, J20.3, J21.3, U2.20 (GPIO12/TOUCH12/ADC2_CH1/FSPICLK/FSPIIO6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), U4.12 (SCK)
/GPIO_13: J1.7, J14.5, J15.7, J20.4, J21.4, U2.21 (GPIO13/TOUCH13/ADC2_CH2/FSPIQ/FSPIIO7/S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), U4.13 (MISO)
/GPIO_14: J1.8, J15.8, J22.5, J26.4, J27.4, U2.22 (GPIO14/TOUCH14/ADC2_CH3/FSPIWP/FSPIDQS/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)
/GPIO_15: J4.5, J7.5, J22.2, J26.1, J27.1, U2.8 (GPIO15/U0RTS/ADC2_CH4/XTAL_32K_P)
/GPIO_16: J4.6, J7.6, J22.3, J26.2, J27.2, U2.9 (GPIO16/U0CTS/ADC2_CH5/XTAL_32K_N)
/GPIO_17: J4.7, J7.7, J12.2, J12.3, J16.1, J16.2, J17.1, J17.2, U2.10 (GPIO17/U1TXD/ADC2_CH6)
/GPIO_18: J4.8, J7.8, J12.4, J12.5, J16.3, J16.4, J17.3, J17.4, U2.11 (GPIO18/U1RXD/ADC2_CH7/CLK_OUT3)
/GPIO_19: J8.2 (D-), U2.13 (GPIO19/U1RTS/ADC2_CH8/CLK_OUT2/USB_D-)
/GPIO_20: J8.3 (D+), U2.14 (GPIO20/U1CTS/ADC2_CH9/CLK_OUT1/USB_D+)
/GPIO_21: J5.1, J23.2, J28.1, J29.1, U2.23 (GPIO21)
/GPIO_38: J5.4, J23.5, J28.4, J29.4, U2.31 (GPIO38/FSPIWP/SUBSPIWP)
/GPIO_39_TCK: U2.32 (MTCK/GPIO39/CLK_OUT3/SUBSPICS1)
/GPIO_40_TDO: U2.33 (MTDO/GPIO40/CLK_OUT2)
/GPIO_41_TDI: U2.34 (MTDI/GPIO41/CLK_OUT1)
/GPIO_42_TMS: U2.35 (MTMS/GPIO42)
/GPIO_45: U2.26 (GPIO45)
/GPIO_46: U2.16 (GPIO46)
/GPIO_47: J5.2, J23.3, J28.2, J29.2, U2.24 (GPIO47/SPICLK_P/SUBSPICLK_P_DIFF)
/GPIO_48: J5.3, J23.4, J28.3, J29.3, U2.25 (GPIO48/SPICLK_N/SUBSPICLK_N_DIFF)
/LED1: J3.1, R8.2
/LED2: J3.2, R9.2
/LED3: J3.3, R10.2
/LED4: J3.4, R11.2
/POT1: J32.1, RV1.2
/POT2: J32.2, RV2.2
/POT3: J32.3, RV3.2
/RTS: Q2.2 (E), R13.1, U1.14 (~RTS)
/U0RXD: R1.2, U2.36 (U0RXD/GPIO44/CLK_OUT2)
/U0TXD: R2.2, U2.37 (U0TXD/GPIO43/CLK_OUT1)
/VBUS: D12.2 (A), J2.1 (VBUS)
/VBUS_OTG: D11.2 (A), J8.1 (VBUS)
/V_EXT: D13.2 (A), J6.2
GND: BT1.1, BT2.1, BT3.1, BT4.1, C1.2, C2.2, C3.2, C4.2, C5.2, C6.2, C7.2, C8.2, C9.2, C10.2, C11.2, C12.2, C13.2, C14.2, D1.1 (K), D7.1 (K), D8.1 (K), D9.1 (K), D10.1 (K), D14.1 (K), J2.5 (GND), J2.6 (Shield), J6.1, J8.5 (GND), J8.6 (Shield), J9.6, J12.6, J13.6, J14.6, J22.6, J23.6, J30.1, J30.2, J30.3, J30.4, J30.5, J30.6, J30.7, J30.8, J33.1, J33.2, J33.3, J33.4, J33.5, J33.6, J33.7, J33.8, RV1.3, RV2.3, RV3.3, SW1.1, SW2.1, U1.1 (GND), U2.1 (GND), U2.40 (GND), U2.41 (GND), U3.1 (GND), U4.1 (GND), U4.2 (GND), U4.9 (GND), U4.16 (GND); also elsewhere on the board
unnamed: D1.2 (A), R3.1
unnamed 56: D7.2 (A), R8.1; also elsewhere on the board
unnamed 57: D8.2 (A), R9.1; also elsewhere on the board
unnamed 58: D9.2 (A), R10.1; also elsewhere on the board
unnamed 59: D10.2 (A), R11.1; also elsewhere on the board
unnamed: D14.2 (A), R14.2
unnamed: Q2.1 (B), R12.2
unnamed: Q3.1 (B), R13.2
unnamed 63: R3.2, S1.6 (NC_4), U4.3 (3.3V); also elsewhere on the board
unnamed: R2.1, U1.3 (RXD)
unnamed: R1.1, U1.2 (TXD)
unnamed: C1.1, U1.16 (VCC)
unnamed: R4.2, U2.2 (3V3)

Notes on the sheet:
Buttons
I2C
RA 02
SPI
REGLETAS GPIOS
Power supply
USB OTG
Simple LEDs
USB
UART
Microcontroller
REGLETAS GND SALIDA 5V
OUT ANSEL,GPIOS
Boot settings
Analog inputs

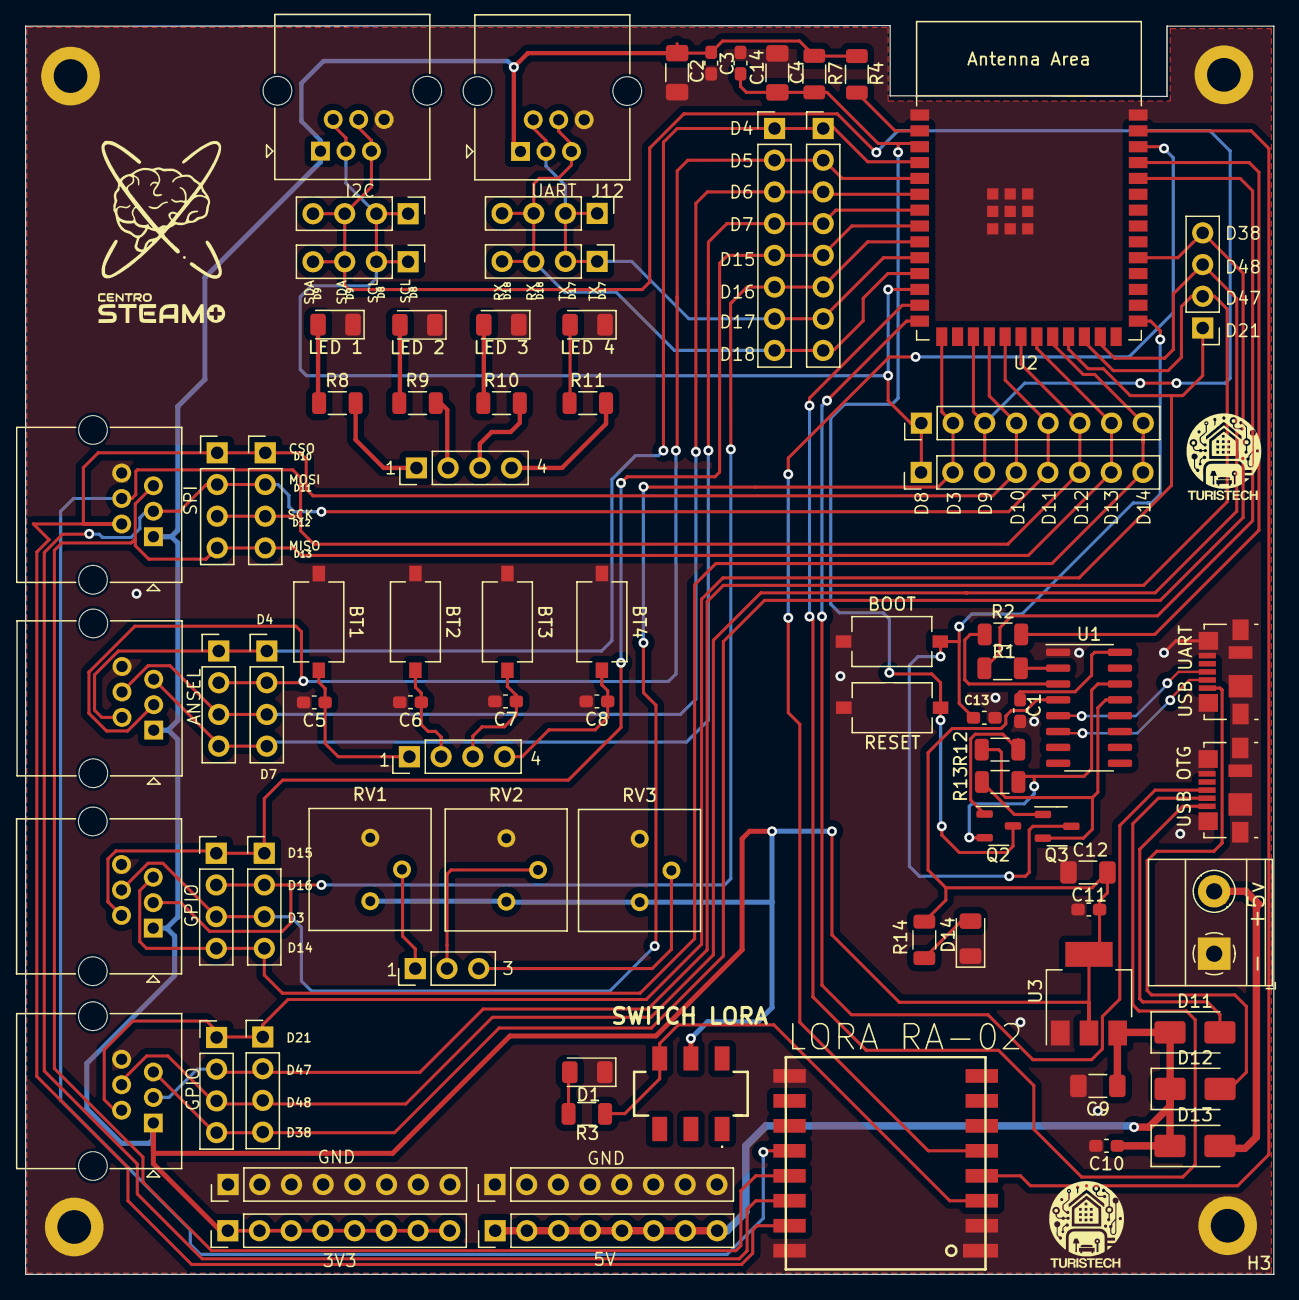
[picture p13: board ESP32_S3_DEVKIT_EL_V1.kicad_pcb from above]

Board: 2 copper layers, 100.0 x 100.0 mm, 85 parts (0 on the bottom side), 62 nets.

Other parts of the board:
BOOT: SW_Push; SW_Tactile_SPST_NO_Straight_CK_PTS636Sx25SMTRLFS
H3: MountingHole_2.7mm_M2.5_DIN965_Pad
LED 1, LED 2, LED 3, LED 4: Blue LED; LED_1206_3216Metric
RESET: SW_Push; SW_Tactile_SPST_NO_Straight_CK_PTS636Sx25SMTRLFS
SWITCH LORA: SLW-913535-2A-SMT; SLW9135352ASMT

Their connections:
+3.3V: SWITCH LORA.5 (COM_2); also elsewhere on the board
/CHIP_PU: RESET.2; also elsewhere on the board
/GPIO0: BOOT.2; also elsewhere on the board
GND: BOOT.1, H3.3, LED 1.1 (K), LED 2.1 (K), LED 3.1 (K), LED 4.1 (K), RESET.1; also elsewhere on the board
unnamed 56: LED 1.2 (A); also elsewhere on the board
unnamed 57: LED 2.2 (A); also elsewhere on the board
unnamed 58: LED 3.2 (A); also elsewhere on the board
unnamed 59: LED 4.2 (A); also elsewhere on the board
unnamed 63: SWITCH LORA.6 (NC_4); also elsewhere on the board

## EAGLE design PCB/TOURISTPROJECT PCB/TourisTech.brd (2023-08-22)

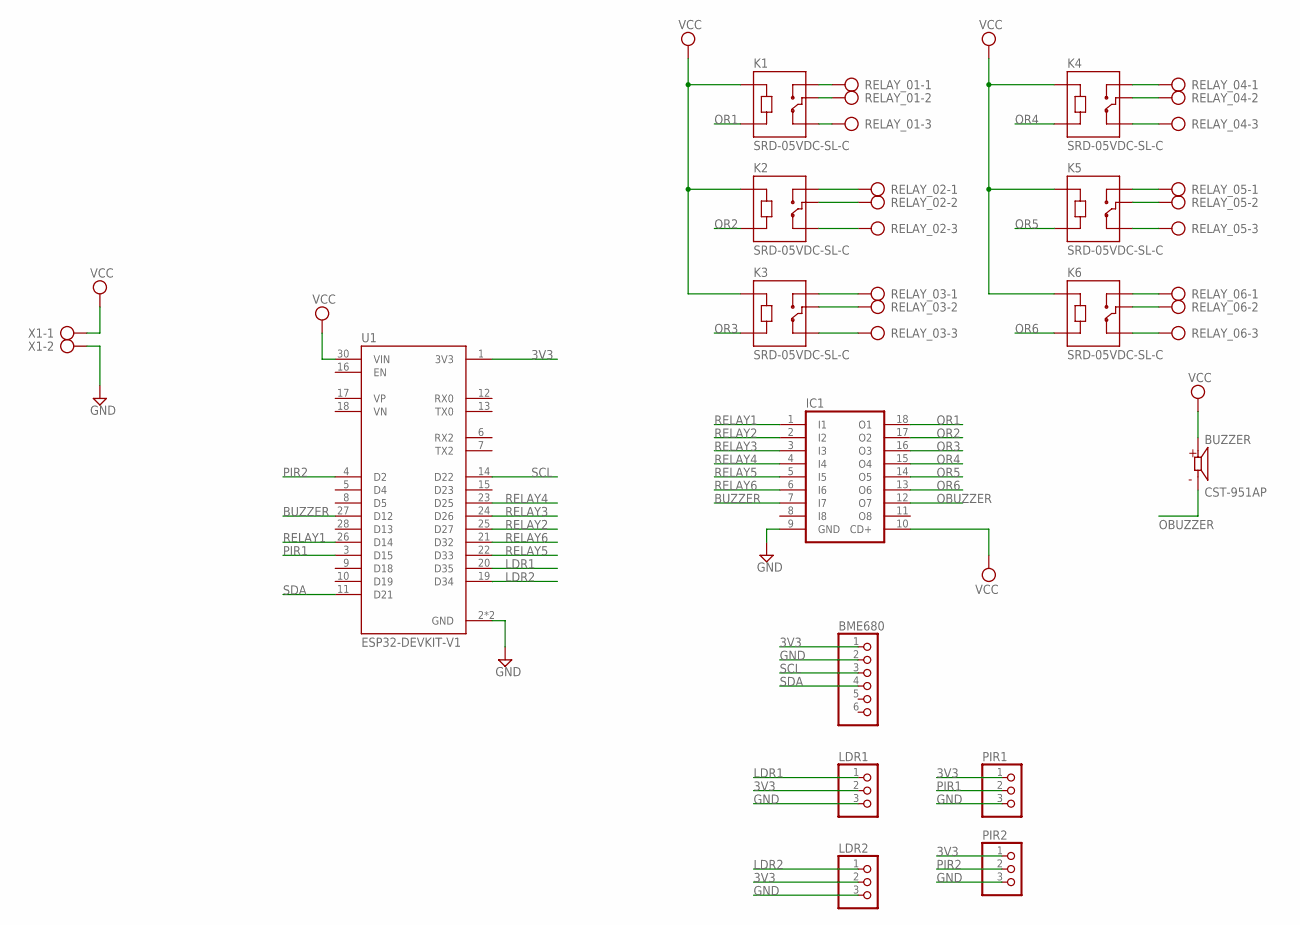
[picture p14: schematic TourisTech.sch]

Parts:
BME680: PINHD-1X6; 1X06
BUZZER: CST-951AP; CUI_CST-951AP
IC1: ULN2803A; DIL18
K1, K2, K3, K4, K5, K6: SRD-05VDC-SL-C; RELAY_SRD-05VDC-SL-C
LDR1, LDR2: PINHD-1X3; 1X03
PIR1, PIR2: PINHD-1X3; 1X03
RELAY_01, RELAY_02, RELAY_03, RELAY_04, RELAY_05, RELAY_06: AK300/3
U1: ESP32-DEVKIT-V1; MODULE_ESP32_DEVKIT_V1
X1: AK300/2

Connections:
3V3: BME680.1, LDR1.2, LDR2.2, PIR1.1, PIR2.1, U1.1 (3V3)
BUZZER: IC1.7 (I7), U1.27 (D12)
GND: BME680.2, IC1.9 (GND), LDR1.3, LDR2.3, PIR1.3, PIR2.3, U1.2 (GND), U1.29 (GND), X1.2
LDR1: LDR1.1, U1.20 (D35)
LDR2: LDR2.1, U1.19 (D34)
unnamed: K1.NO, RELAY_01.1
unnamed: K1.COM, RELAY_01.2
unnamed: K1.NC, RELAY_01.3
unnamed: K2.NO, RELAY_02.1
unnamed: K2.COM, RELAY_02.2
unnamed: K2.NC, RELAY_02.3
unnamed: K3.NO, RELAY_03.1
unnamed: K3.COM, RELAY_03.2
unnamed: K3.NC, RELAY_03.3
unnamed: K4.NO, RELAY_04.1
unnamed: K4.COM, RELAY_04.2
unnamed: K4.NC, RELAY_04.3
unnamed: K5.NO, RELAY_05.1
unnamed: K5.COM, RELAY_05.2
unnamed: K5.NC, RELAY_05.3
unnamed: K6.NO, RELAY_06.1
unnamed: K6.COM, RELAY_06.2
unnamed: K6.NC, RELAY_06.3
OBUZZER: BUZZER.M, IC1.12 (O7)
OR1: IC1.18 (O1), K1.A2
OR2: IC1.17 (O2), K2.A2
OR3: IC1.16 (O3), K3.A2
OR4: IC1.15 (O4), K4.A2
OR5: IC1.14 (O5), K5.A2
OR6: IC1.13 (O6), K6.A2
PIR1: PIR1.2, U1.3 (D15)
PIR2: PIR2.2, U1.4 (D2)
RELAY1: IC1.1 (I1), U1.26 (D14)
RELAY2: IC1.2 (I2), U1.25 (D27)
RELAY3: IC1.3 (I3), U1.24 (D26)
RELAY4: IC1.4 (I4), U1.23 (D25)
RELAY5: IC1.5 (I5), U1.22 (D33)
RELAY6: IC1.6 (I6), U1.21 (D32)
SCL: BME680.3, U1.14 (D22)
SDA: BME680.4, U1.11 (D21)
VCC: BUZZER.P, IC1.10 (CD+), K1.A1, K2.A1, K3.A1, K4.A1, K5.A1, K6.A1, U1.30 (VIN), X1.1

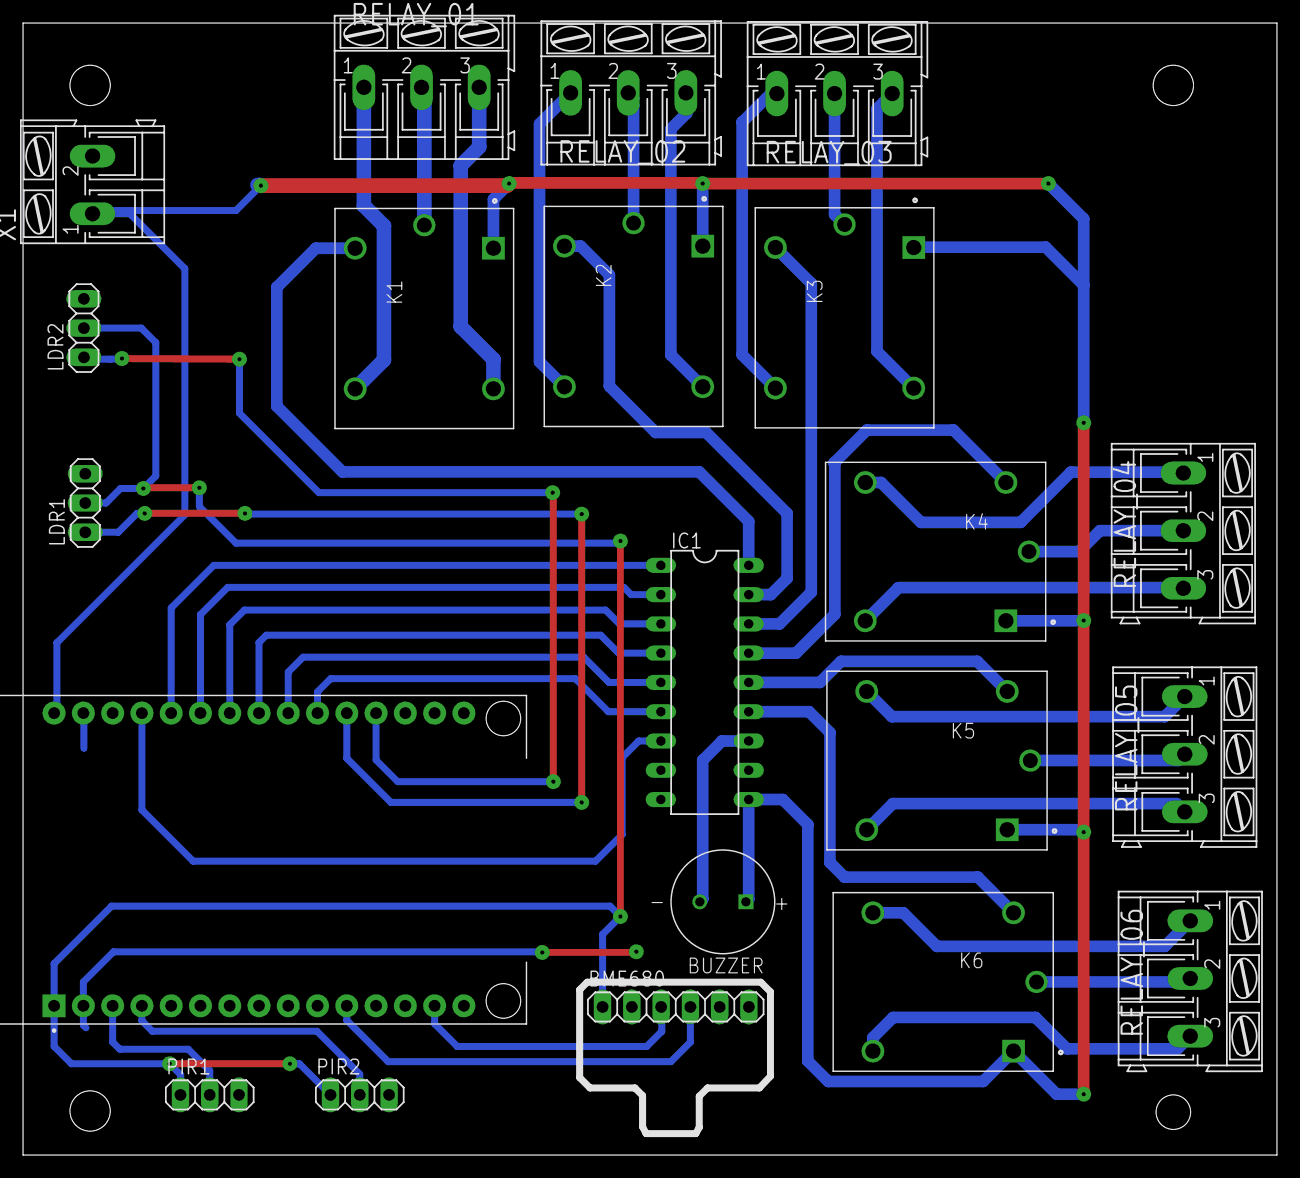
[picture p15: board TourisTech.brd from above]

Board: 2 copper layers, 108.8 x 98.2 mm, 21 parts (0 on the bottom side), 41 nets.

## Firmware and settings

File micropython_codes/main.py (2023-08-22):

from machine import Pin, I2C
from time import sleep
from bme680 import *
from TuristProject import *
from ESP_Connection import *

list_relay_connection = [14,27,26,25,33,32]

RELAY1=0
RELAY2=1
RELAY3=2
RELAY4=3
RELAY5=4
RELAY6=5

MY_SSID  = getSSID()
MY_PASS  = getPASS()
MY_TOKEN = getToken()

time_to_send = 3000


def run():
    global time_to_send
    counter_sample = 0
    wifi = ESP_Connect(SSID=MY_SSID, PASS= MY_PASS)
    wifi.connect_ubidots(MY_TOKEN)
    
    i2c = I2C(1, scl=Pin(22), sda=Pin(21), freq=100000)
    bme = BME680_I2C(i2c=i2c)
    ldr_interior = LDR(pinldr=34)
    ldr_exterior = LDR(pinldr=35)
    pirA = PIR(pinpir=15)
    pirB = PIR(pinpir=2)
    relays = RELAY(list_relays =list_relay_connection )
    buzzer = BUZZER(pin_buzzer=12)
    
    buzzer.play_buzzer(5)
    relays.set_relay(RELAY1)
    relays.set_relay(RELAY4)
    while True:
        
        
        
        ldr_int_val = ldr_interior.get_ldr_Value()
        ldr_ext_val = ldr_exterior.get_ldr_Value()
        
        pirA_val = pirA.get_pir_Value()
        pirB_val = pirB.get_pir_Value()
        
        temp = bme.temperature
        hum  = bme.humidity
        pres = bme.pressure
        gas  = bme.gas
        
        if counter_sample == time_to_send:
            wifi.publish_ubidots(typeVar="Temperature",value=temp,context="AulaSteam")
            wifi.publish_ubidots(typeVar="Humidity",value=hum,context="AulaSteam")
            wifi.publish_ubidots(typeVar="Pressure",value=pres,context="AulaSteam")
            wifi.publish_ubidots(typeVar="Gas",value=gas,context="AulaSteam")
            
            counter_sample = 0
        
        print("Temp: ",temp)
        print("Hum: ",hum)
        print("Pres: ",pres)
        print("Gas: ",gas)
        print("")
        print("LDR INT: ",ldr_int_val)
        print("LDR EXT: ",ldr_ext_val)
        print("")
        print("PIR A: ",pirA_val)
        print("PIR B: ",pirB_val)
        print("")
        counter_sample += 1
        sleep(0.3)
        
        


if __name__=="__main__":
    run()

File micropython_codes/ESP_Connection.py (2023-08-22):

import network
from time import sleep


from umqtt.robust import MQTTClient

class ESP_Connect():
    
    def __init__(self, SSID, PASS):
        self.SSID = SSID
        self.PASS = PASS
        self.sta_if = network.WLAN(network.STA_IF)
        self.sta_if.active(True)
        self._checkwifi()
    
    def _checkwifi(self):
        
        if not self.sta_if.isconnected():
            self.sta_if.connect(self.SSID, self.PASS)
            # Espera a que se establezca la conexión
            while not self.sta_if.isconnected():
                pass
            print('Conexión establecida a la red WiFi')
            print('Dirección IP:', self.sta_if.ifconfig()[0])
        else:
            print("El sistema ya esta conectado a una red wifi")
           
    def connect_ubidots(self, token):
        self.ubidotsToken = token 
        self.DEVICE_LABEL = "TourisTec"
        
    def publish_ubidots(self, typeVar, value, context):
        
        self.client = MQTTClient(self.DEVICE_LABEL,
                                 "industrial.api.ubidots.com",
                                 1883,user = self.ubidotsToken,
                                 password = self.ubidotsToken)
        self.client.connect()
        
        self.msg =  b'{"%s": {"value":%s, "context":"%s"}}' %(typeVar,value, context)
        self.topic = b"/v1.6/devices/{device_label}".format(device_label=self.DEVICE_LABEL)
        self.client.publish(self.topic, self.msg)
        print("msg: ", self.msg)
        print("topic: ", self.topic)
        self.client.disconnect()
        sleep(5)    
        
        

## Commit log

2023-08-22 Se agregan archivos de PCB y codigos de Python FUncionando@
    [TourisTech.brd, TourisTech.sch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]
2023-08-22 Se actualiza codigo con Credenciales de Ubidots Julian
2024-03-20 PCB - PLACA MADRE
    [ESP32_S3_DEVKIT_EL_V1.csv, ESP32_S3_DEVKIT_EL_V1.kicad_pcb, ESP32_S3_DEVKIT_EL_V1.kicad_sch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]
2024-04-03 Ultima PCB
    PCB Final
    [ESP32_S3_DEVKIT_EL_V1.kicad_pcb]
2024-04-06 Nueva version del esquematico de la placa
    La unica modificacion que hice fue organizar un poco mejor el esquematico, osea el archivo .kicad_sch
    [ESP32_S3_DEVKIT_EL_V1.kicad_sch]
2024-04-06 Version de frabricacion 01
    [ESP32_S3_DEVKIT_EL_V1-B_Cu.gbr, ESP32_S3_DEVKIT_EL_V1-B_Mask.gbr, ESP32_S3_DEVKIT_EL_V1-B_Paste.gbr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]
2024-04-12 Se agregan modelos 3D
    [CircuitWorks-CERMET TRIMMER SINGLE TURN 10MM 500MW TOP ADJUST 1.STEP, CircuitWorks-CERMET TRIMMER SINGLE TURN 10MM 500MW TOP ADJUST.STEP, LM393D.STEP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]
2024-04-12 Se agrega PCB del modulo 01
    [CJMCU-680.SLDPRT, G3MB-202P.step, ProyectoTuristech.kicad_pcb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]
